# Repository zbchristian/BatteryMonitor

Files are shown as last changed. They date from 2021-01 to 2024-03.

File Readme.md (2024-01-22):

Battery Monitor with low energy Bluetooth readout
=================================================
Measure and display the 
- capacity in Ampere hours (Ah) of a battery
- the voltage of the battery (V)
- the current flowing from/to the battery (A)

of a camper/mobil home 12V battery on an Android Smartphone.

The monitor is based on three modules (DC-DC converter, ESP32, ADS1115), which are placed either on a bread board or a PCB. 
The schematic and the layout of this base board can be found in the Eagle folder.

Depending on the used firmware, the device pulls about 10mA (25mA) from the 12V battery. An additional 8-9mA are drawn by the Hall current sensor.

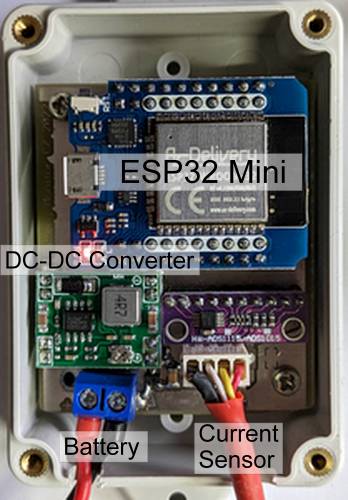
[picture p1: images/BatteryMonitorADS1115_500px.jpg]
Prototype Prototype of the Battery Monitor

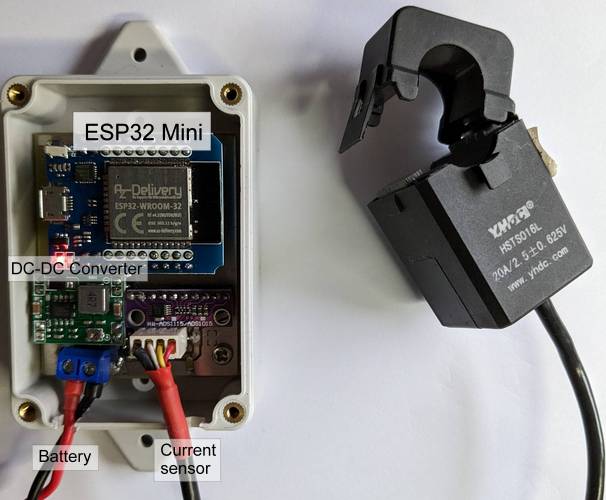
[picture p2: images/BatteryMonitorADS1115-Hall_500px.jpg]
Prototype with Hall sensor Prototype of the Battery Monitor with split core current sensor

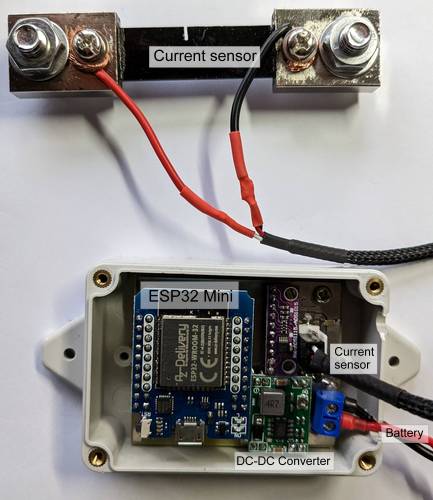
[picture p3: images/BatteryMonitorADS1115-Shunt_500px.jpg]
Prototype with shunt Prototype of the Battery Monitor with shunt


Hardware
========
* ESP32 board (Mini)
* Current sensor (Hall sensor to measure the magnetic field, or shunt resistor) 
* Step-down regulator (DC-DC Buck converter)
  * Input: 10V-20V
  * Output: 5.8V (adjustable version)
  * Max. current: 1A
* ADS1115 16 bit ADC

The 5.8V output voltage of the DC-DC converter is due to the fact, that the current sensor (Hall sensor) and the ADC require very stable 5V. 
This is provided by the 5V regulator MCP1702/1703. The ESP32 module has its own 3.3V regulator and can handle up to 6V on the Vcc pin. 

For a version utilizing the internal ADC, see the [Readme](Readme_internalADC.md).

Current Sensor
==============
A split core current sensor with a Hall sensor or a shunt resistor is used to measure the current.

Hall Sensor
-----------
Advantage: sensor works contactless. No need to mess with the cabling, since the sensor is just placed around one of the battery cables.

Utilized model: YHDC HSTS016L +-20A
- 2.5+-0.625V 
- reference voltage 2.5V

Shunt Resistor
--------------
A commercial shunt suitable for a high current (e.g. 100A) is placed into the ground connection to the battery. The voltage drop is small (e.g. 70mV for 100A).
The ADS1115 allows to change the voltage range down to +-256mV. This makes it suitable to measure the current with sufficient precision, without the need of an additional amplifier.

The reached resolution is for both cases about 50mA.

Analog to digital conversion
============================
The ADC ADS1115 with 16 bit resolution is readily available as a module. It exhibits 4 channels, a wide adjustable voltage range, a build in amplifier and can directly measure voltage differences.  

Android APP
===========
Developed with the MIT App-Inventor2
- Low energy bluetooth (BLE) connection to the ESP32
- Main Screen with current, voltage, capacity
- Settings window 

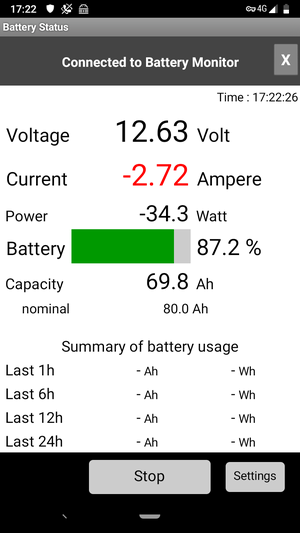
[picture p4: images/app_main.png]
Battery Monitor APP main screen Battery Monitor APP - main screen

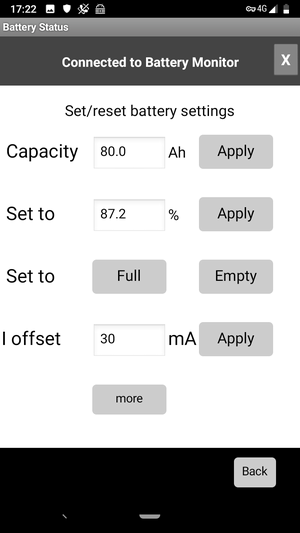
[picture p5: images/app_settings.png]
Battery Monitor APP settings Battery Monitor APP - settings


Software
========
The Arduino IDE is used for the code development. 
Three different versions of the ESP32 firmware exist:
- Utilize the internal ADC ([code](./BatteryMonitor_internal_ADC/BatteryMonitor_internal_ADC.ino))
- Utilize an ADS1115 external ADC ([code](./BatteryMonitor_ADS1115/BatteryMonitor_ADS1115.ino))
- UTilize an ADS1115 external ADC and reduce the power by going into the light sleep mode of the ESP32 The ([code](./BatteryMonitor_lowpower/BatteryMonitor_lowpower.ino))

Requires packages
-----------------
- ESP32 support with BLE and Wire
- ADS1115_WE by Wolfgang Ewald

Concept
-------
- Settings: define time intervals and used channels in the `#define` section of the code
- Setup: reduce CPU clock to save power, setup timers and the external ADC
- Loop: Read the battery voltage and current, calculate the Ah and power and store current battery state to flash
- The BLE connection is initialized by the phone
- A sign-on message is expected by the ESP32. This is a hash value of the current time (salt) and a pre-shared pass phrase. 
- If the message is not received, the BLE connection is terminated.
- For the first 60 seconds the connection is possible without the passphrase
- Data are send to the APP every second as a block of 20 bytes. The values are 16 bit integer values, which have been scaled to reflect the predefined number of significant digits. 

The versions differ mainly in the way the timing is handled. 

The first two versions utilize a 1msec timer interrupt to define time intervals and trigger time dependent 
actions (reading the voltage/current value, calculate battery capacity, transmit via BT). 

The third version handles the timing once per loop() iteration: 
- the loop is running once every 100msec
- the corresponding delay is done either as a standard delay (BT activated) or by the ´light sleep´ mode (BT off) of the ESP32. 
These states are alternating with 5sec BT off and 1sec BT on until a phone connects.
- while BT is off, the CPU frequency is reduced from 80 Mhz down to 20 MHz, which saves an additional 3-4mA @ 12V

In total this reduces the required current from about 25mA down to approx 4mA @ 12V, when the device is in idle mode (BT off). 

Status Printout of the Device
-----------------------------
An USB connection to the ESP32 allows to view the status print out of the device. Connect a terminal program to the corresponding virtual serial port (e.g. COM port).
The measured values and status infomrmations are printed to the terminal and allow to perform the calibration of the sensors.  

Calibration
===========
The calibration of the battery voltage and current measurement is required.

Battery Voltage
---------------
The measured voltage might vary due to resistor variations. The default voltage divider reduces the voltage by a factor of 0.25 ( 10k/(10k+30k) ). 
This factor is defined as `R12V`.
In addition a small voltage offset might be present. This should be measured with a good voltage meter and the corrections entered into the source code 
function `Vcal12`.

Current Sensor
--------------
A Hall sensor contains active components and the voltage to current conversion should be checked. An voltage offset leads to a none zero current displayed for 0 Amps.
The printout messages on a connected terminal allows to compare the measured values with the applied voltage/current. Enter the corrected values into the functions `VcalSensor` and `V2Amps`. 
Non linear dependencies might be entered into the latter function as well. 

Misc
====
On the PCB three additional IO pins are available on pin headers (IO2, IO4, IO5). These are not yet utilized and can be used to attach more hardware. The pin header for 
IO5 provides in addition 3.3V, which can be used to connect an active touch button (e.g. based on the TTP223 chip).

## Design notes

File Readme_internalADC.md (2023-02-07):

Battery Monitor with low energy Bluetooth readout
=================================================
Measure and display the 
- capacity in Ampere hours (Ah) of a battery
- the voltage of the battery (V)
- the current flowing from/to the battery (A)

of a camper/mobil home 12V battery on an Android Smartphone.

Prototype exists, but the schematic not completed yet.

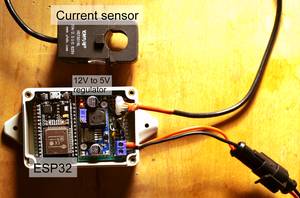
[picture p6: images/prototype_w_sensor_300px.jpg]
Prototype Prototype of the Battery Monitor

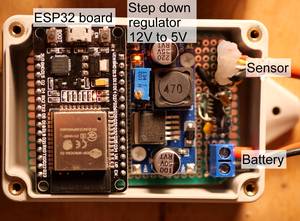
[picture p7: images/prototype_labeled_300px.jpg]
Prototype close up Prototype of the Battery Monitor (close up)


Hardware
========
* ESP32 board
* Current sensor to measure the magnetic field or a shunt resistor 
* Step-down regulator (DC-DC Buck converter)
  * Input: 10V-20V
  * Output: 5V (fixed or adjustable)
  * Current: 1A
* Dual OpAmp

Current Sensor
==============
A split core current sensor with a Hall sensor is used to measure the current.

Advantage: sensor works contactless. No need to mess with the cabling, since the sensor is just placed around one of the battery cables.

Utilized model: YHDC HSTS016L +-20A
- 2.5+-0.625V (buffered by an OpAmp) 
- reference voltage 2.5V (buffered by an OpAmp) 

The reached resolution is about 50mA.

Analog to digital conversion
============================
Internal 12-bit ADC of the ESP32 processor. The ADC is quite noisy and an averaging (low pass filter) is used in the software 
in order to achieve the resolution of about 50mA.

Android APP
===========
Developed with the MIT App-Inventor2
- Low energy bluetooth (BLE) connection to the ESP32
- Main Screen with current, voltage, capacity
- Settings window 

Battery Monitor APP main screen Battery Monitor APP - main screen
Battery Monitor APP settings Battery Monitor APP - settings

Software
========
The Arduino IDE is used for the code development.

- The BLE connection is initialized by the phone
- A sign-on message is expected by the ESP32. This is a hash value of the current time (salt) and a pre-shared pass phrase. 
- If the message is not received, the BLE connection is terminated.
- Data are send to the APP every second as a block of 20 bytes. The values are 16 bit integer values, which have been scaled to reflect the predefined number og significant digits.

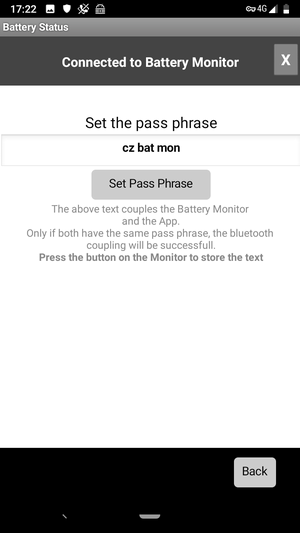
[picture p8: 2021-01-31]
images/app_passphrase.png

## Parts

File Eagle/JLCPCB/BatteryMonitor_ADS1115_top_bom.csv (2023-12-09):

Comment | Designator | Footprint | LCSC Part #
1k | R3 R4 R5 | R1206
1u | C2 C3 C5 | C1206
2u | C4 C7 | C1206
10k | R2 | R1206
33k | R1 | R1206
100n | C1 | C1206
CGRM4001-G | D1 | SOD-123_MINI-SMA
MCP1703CB | IC1 | SOT23

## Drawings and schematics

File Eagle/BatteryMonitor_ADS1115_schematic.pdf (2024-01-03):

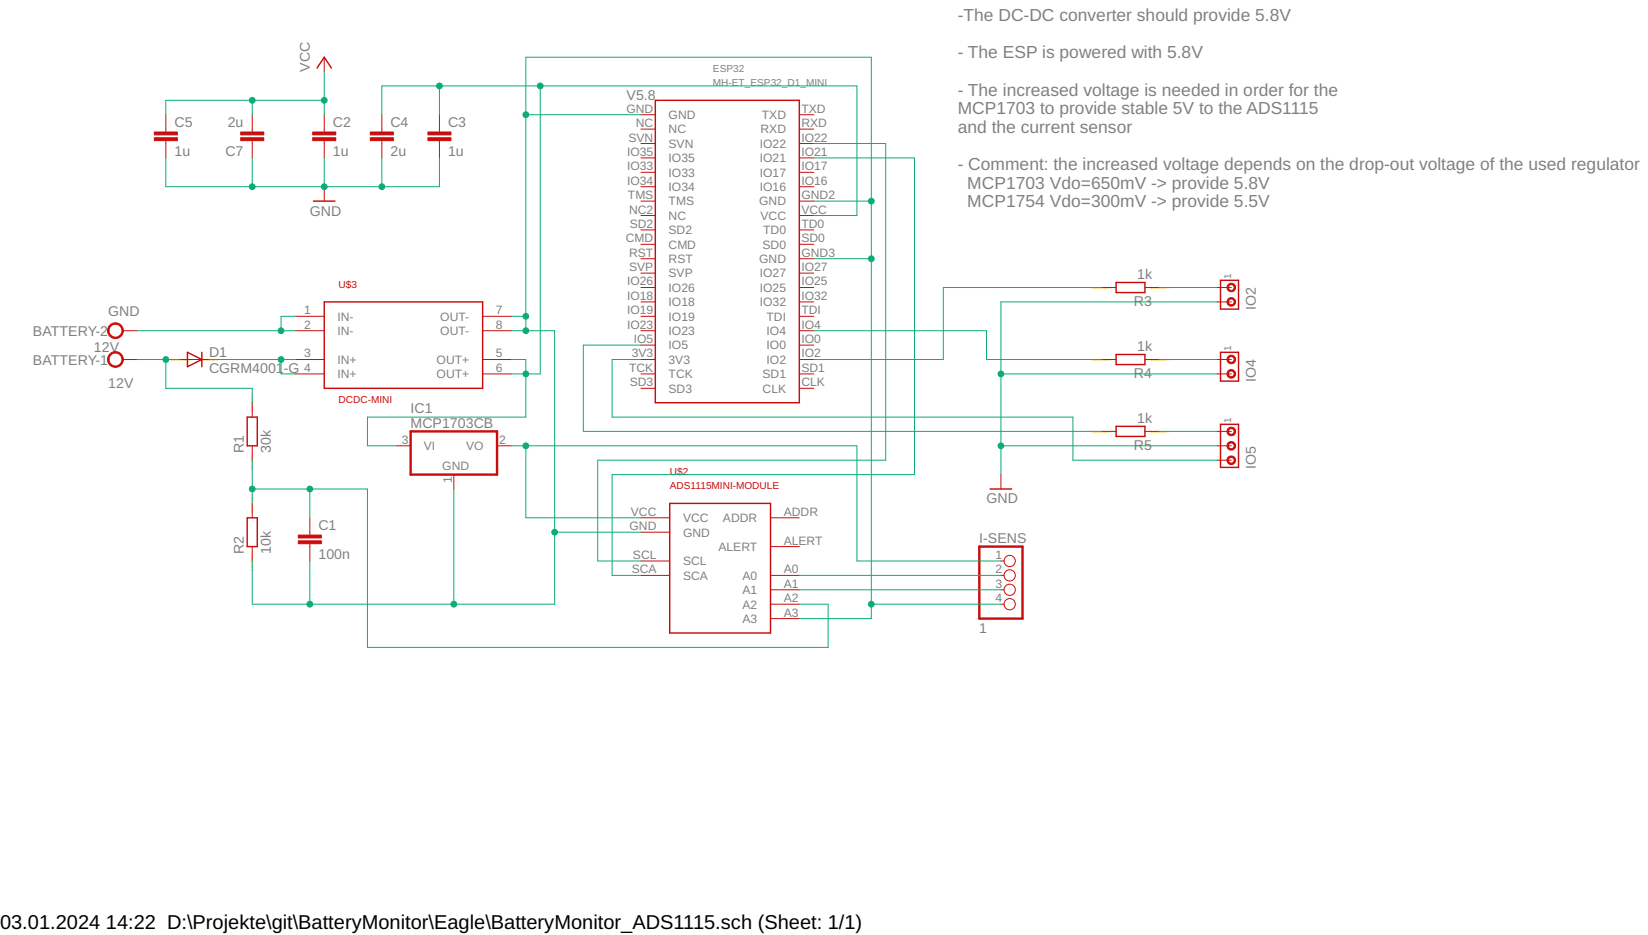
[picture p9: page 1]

-The DC-DC converter should provide 5.8V

- The ESP is powered with 5.8V

- The increased voltage is needed in order for the
MCP1703 to provide stable 5V to the ADS1115
and the current sensor

IO21
IO17

- Comment: the increased voltage depends on the drop-out voltage of the used regulator
MCP1703 Vdo=650mV -> provide 5.8V
MCP1754 Vdo=300mV -> provide 5.5V

VCC

SpiceOrder 1 SpiceOrder 2

03.01.2024 14:22 D:\Projekte\git\BatteryMonitor\Eagle\BatteryMonitor_ADS1115.sch (Sheet: 1/1)

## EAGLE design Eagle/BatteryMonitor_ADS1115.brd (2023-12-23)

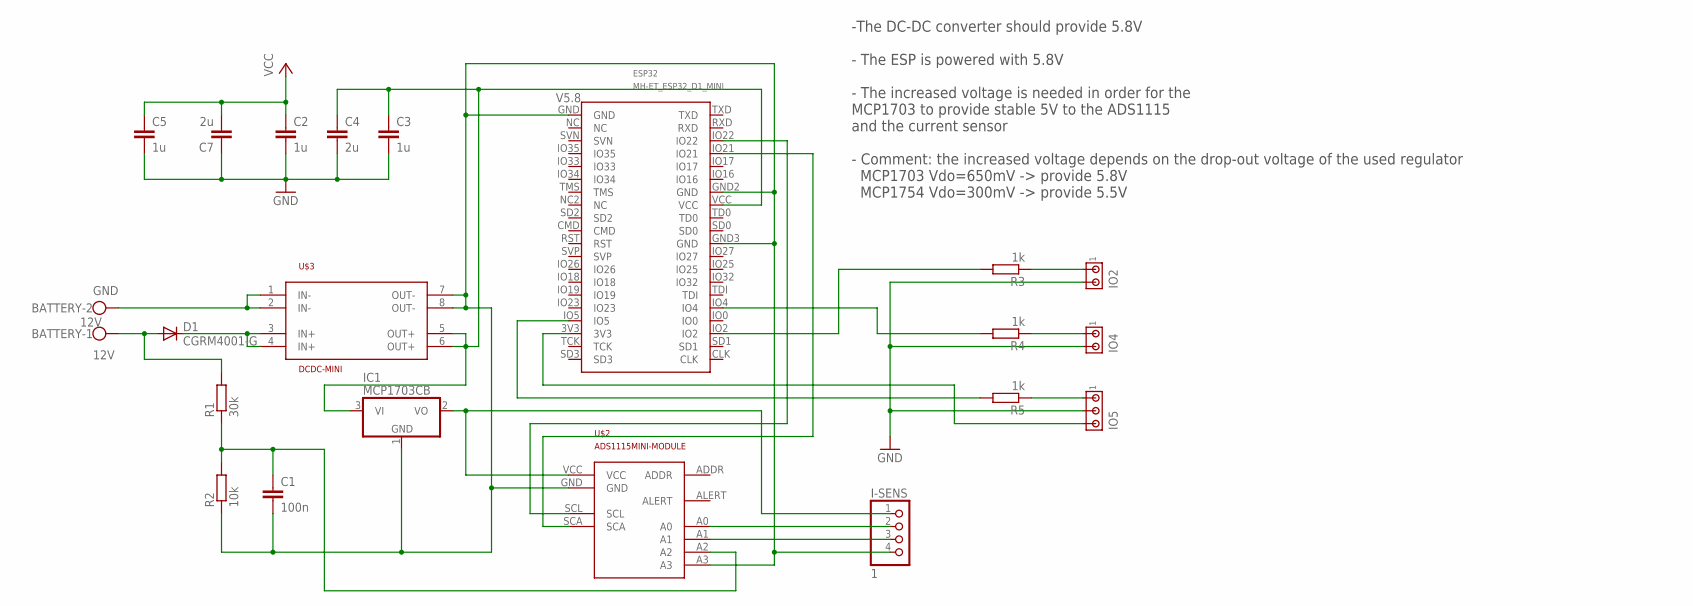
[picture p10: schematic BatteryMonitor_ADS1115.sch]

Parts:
BATTERY: 12V; W237-102
C1: 100n; C1206
C2, C3, C5: 1u; C1206
C4, C7: 2u; C1206
D1: CGRM4001-G; SOD-123_MINI-SMA
ESP32: MH-ET_ESP32_D1_MINI
I-SENS: 1; 1X04/90
IC1: MCP1703CB; SOT23
IO2, IO4: MTA02-100; 10X02MTA
IO5: MTA03-100; 10X03MTA
R1: 30k; R1206
R2: 10k; R1206
R3, R4, R5: 1k; R1206
U$2: ADS1115MINI-MODULE; ADS1115
U$3: DCDC-MINI

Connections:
12V: BATTERY.1, D1.A, R1.2
GND: BATTERY.2, C1.2, C2.2, C3.2, C4.2, C5.2, C7.1, ESP32.GND, ESP32.GND2 (GND), ESP32.GND3 (GND), I-SENS.4, IC1.1 (GND), IO2.2, IO4.2, IO5.2, R2.1, U$2.A3, U$2.GND, U$3.1 (IN-), U$3.2 (IN-), U$3.7 (OUT-), U$3.8 (OUT-)
unnamed: IO5.1, R5.1
unnamed: ESP32.IO2, R3.2
unnamed: ESP32.IO4, R4.2
unnamed: I-SENS.2, U$2.A0
unnamed: ESP32.IO5, R5.2
unnamed: I-SENS.3, U$2.A1
unnamed: ESP32.IO21, U$2.SCA
unnamed: ESP32.IO22, U$2.SCL
unnamed: C1.1, R1.1, R2.2, U$2.A2
unnamed: IO4.1, R4.1
unnamed: IO2.1, R3.1
unnamed: ESP32.3V3, IO5.3
V5.8: C3.1, C4.1, ESP32.VCC, IC1.3 (VI), U$3.5 (OUT+), U$3.6 (OUT+)
V12: D1.C, U$3.3 (IN+), U$3.4 (IN+)
VCC: C2.1, C5.1, C7.2, I-SENS.1, IC1.2 (VO), U$2.VCC

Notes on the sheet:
-The DC-DC converter should provide 5.8V - The ESP is powered with 5.8V - The increased voltage is needed in order for the MCP1703 to provide stable 5V to the ADS1115 and the current sensor - Comment: the increased voltage depends on the drop-out voltage of the used regulator MCP1703 Vdo=650mV -> p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

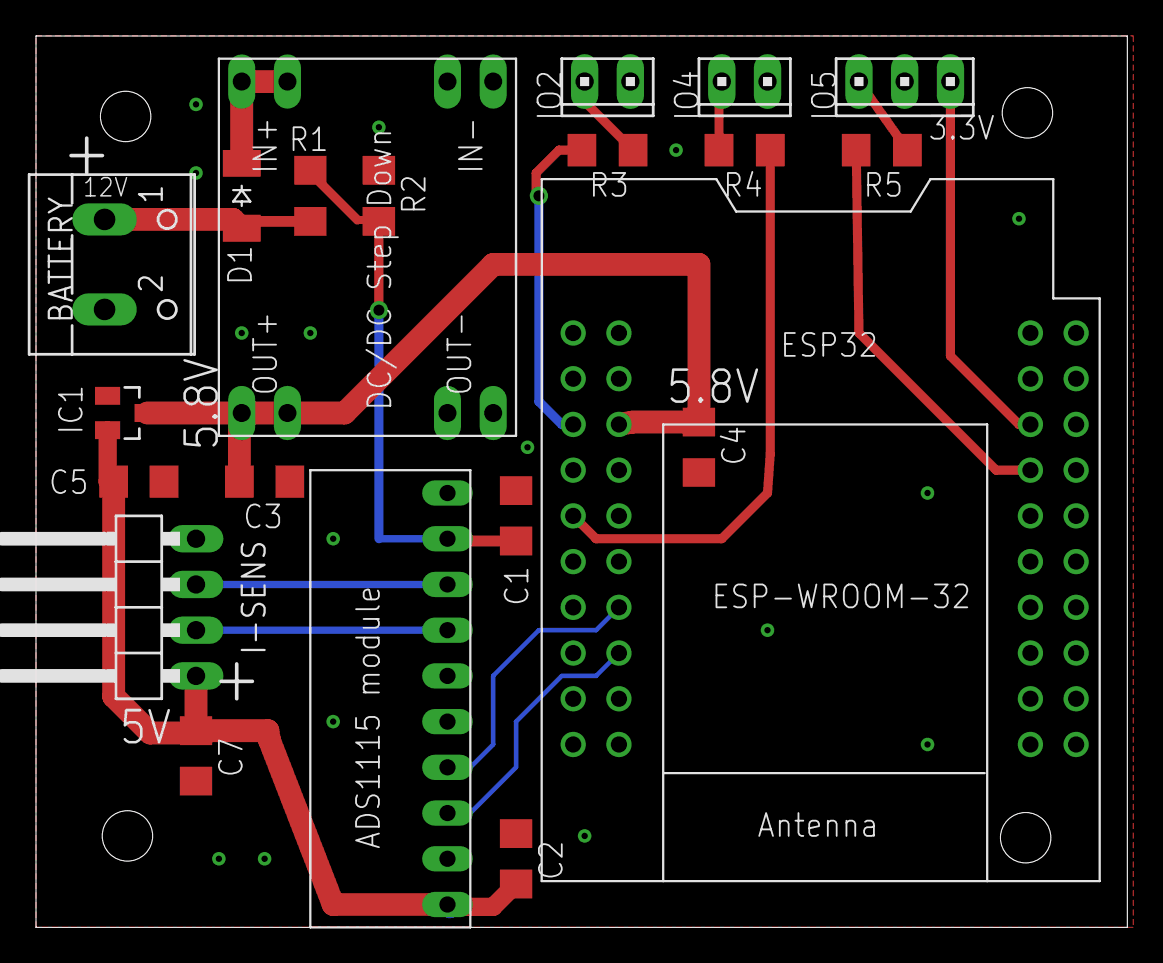
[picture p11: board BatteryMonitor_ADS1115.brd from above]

Board: 2 copper layers, 60.6 x 49.5 mm, 21 parts (0 on the bottom side), 17 nets.

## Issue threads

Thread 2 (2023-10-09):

How to Use Shunt

thinkupplus, 2023-10-09:
We want to find voltage and current values using shunt resistance.
How do I wire the shunt resistor connection? It's hard to tell from the image.
Where should I connect to 0,1,2,3 of ADS1115?
And even if I save the capacity in the app, it is not reflected?
What did I do wrong?

zbchristian, 2023-10-09:
How to attach the shunt: in the program you find `adc_sensor` defined as the difference between channel 0 and channel 1 of the ADC.

The inputs of the ADC are:
A0: Sensor
A1: Sensor
A2: battery voltage
A3: GND

Not sure what you mean, that the capcaity is not reflected in App. Please be more specific.
Does the App connect to the device? What is visible on the display?

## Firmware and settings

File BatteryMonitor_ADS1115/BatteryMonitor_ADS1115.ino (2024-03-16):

/*
BATTERY MONITOR WITH CURRENT SPLIT CORE WITH HALL SENSOR
========================================================
Sensor model YHDC HSTS016L or a shunt resistor

ADC: ADS1115 module via I2C
- Powered by 5V
- Voltage range 4V (Hall sensor) or 256mV (shunt resistor)

- Channel A3 - GND
- Channel A2 - 12V battery voltage (divided by (10+30)/10=4.0) = approx 3V
- Channel A1 - reference voltage of the sensor (nom. 2.5V) 
- Channel A0 - Sensor reading typically 2.5V +- 0.625V or +-75mV (shunt)

Precision: noise of hall sensor allows for about 50mA precision

Values are transmitted via Low Energy Bluetooth to a smartphone app
- all values in uint16 format
- voltage (V) * 100
- current (A) * 100
- power (W) * 10
- nominal and current battery capacity (Ah) * 10
- percentage available (%) * 10

Nominal and current capacity are stored in FLASH memory every 30 seconds

Commands accepted over BLE (string)
===================================
s100 - set current capacity to 100% (full)
s000 - set current capacity to 0% (empty)
scxxxxxx - set nominal capacity to xxxxxx/10 Ah
s%xxxx - set percentage of the current capacity to xxxx/10% (e.g. s%785 -> 78.5%)
soxxxx - set the current offset in milli Amps
sixxxx - set the pre-shared pass phrase used for the hash value of the sign on message (max 9 characters)
ghxxxx - get history data (xxxx = time window in secs, if 0 : send all data) 


THE BATTERY MONITOR DEBUG INFOS
===============================
Connect the ESP32 via USB to a computer and open a terminal program and connect to 
the corresponding serial interface (e.g. COM port)

CZ July 2020/2023

*/

// set the sensor type
//#define CURRENT_SHUNT
#define CURRENT_HALL

#include <stdlib.h>

#include <BLEDevice.h>
#include <BLEUtils.h>
#include <BLEScan.h>
#include <BLEAdvertisedDevice.h>
#include <BLEServer.h>
#include <BLE2902.h>

#include "esp32-hal-cpu.h"

#include "mbedtls/md.h"

/*
extern "C" {
  #include "soc/syscon_struct.h"
}
#include "soc/sens_struct.h"
#include <driver/adc.h>
#include "esp_adc_cal.h"
*/

#include<ADS1115_WE.h> 
#include<Wire.h>
#define I2C_ADDRESS 0x48

#include <Preferences.h>
Preferences persistentStore;  // provides access to the Flash memory


#ifndef CURRENT_HALL
#define CURRENT_CURRENT
#endif
#ifndef CURRENT_SHUNT
#define CURRENT_HALL
#endif

int16_t scale16(float ,float );
void clearStats(void);
void calcStats();

BLEServer *pServer=NULL;
BLEService *pService=NULL;
BLECharacteristic *pCharacteristic_rx;
BLECharacteristic *pCharacteristic_tx;

bool deviceConnected = false;

ADS1115_WE adc = ADS1115_WE(I2C_ADDRESS);

const ADS1115_MUX adc12V        = ADS1115_COMP_2_3; // Diff channel 2 and 3: Battery Voltage
const ADS1115_MUX adcSensor     = ADS1115_COMP_0_1; // Diff channel 0 and 1 : Sensor signal

const ADS1115_RANGE RangeV12    = ADS1115_RANGE_4096;
#ifdef CURRENT_HALL
const ADS1115_RANGE RangeSensor = ADS1115_RANGE_4096;
#else
const ADS1115_RANGE RangeSensor = ADS1115_RANGE_0256;
#endif

#define LED     LED_BUILTIN
#define BUTTON  GPIO_NUM_0   // this is the boot button - NOT AVAILABLE in ESP32 mini modules

hw_timer_t * msTimer = NULL;

DRAM_ATTR unsigned long msTime;
unsigned long deltaTime=0;
unsigned long msLast=0;

#define DefaultSignOnMsg  "123456"   // pre-shared message (max 9 characters) for which a sha256 hash is send by the client
#define maxSignonLen      10

#define currentBin        0.05       // current only displayed in units of 50mA

#define R12V              0.25      // measured - ideal 10/(10+30)=1/4

#define chargeEff		      0.95	    // charging efficiency - AGM/GEL: ~95% , standard lead acid: ~80%

// define time (ms) between the execution of certains functional codes
#define doSave            30000 // ms to save data to EPPROM 
#define doADC             300   // ms to read data from ADC
#define doLED             350   // ms to toggle the LED 
#define doBLE             2000  // ms to send data over BLE
#define doDelay           10    // ms to sleep in LOOP
#define waitSignon        2000  // ms to wait for the signon message

#define timeNoSignon 60000 // ms to wait for a connection without signon message (starts when button is pressed or after reset)

DRAM_ATTR boolean   isSave=false;
DRAM_ATTR boolean   isADC=false;
DRAM_ATTR boolean   isLED=false;
DRAM_ATTR boolean   isBLE=false;
DRAM_ATTR boolean   isAVR=false;
DRAM_ATTR boolean   isValidClient;
DRAM_ATTR int       countSignon;
DRAM_ATTR long      countNoSignon;
DRAM_ATTR boolean   isNoSignon;
DRAM_ATTR int       ncharSignon;
DRAM_ATTR boolean   isReceiveSignon;

float  fCPU;  // CPU frequency in MHz

double filtered12V = -1.0;
double filteredSensor= -1.0;
double BatCapNominal=0.0;
double BatCap  = 0.0;   
double BatIoff = 0.0;
double VBat    = 0.0;
double AmpsBat = 0.0;

const unsigned int timeHistory = 7*24*60*60*1000; // length of history in milli seconds - 7 days
const unsigned int histBin     = 6*60*1000;       // store average values for every n ms - 6 min
const unsigned int nhistory    = timeHistory/histBin; // # of values to store for the timeHistory

float *histAmps;
float *histAh;
float *histVolts;
float avrAmps = 0.0;
float avrAh   = 0.0;
float avrVolts= 0.0;
float statAh[4]   = {-10000.0,-10000.0,-10000.0,-10000.0};  // Ah store statistic for 1h, 6h, 12h and 24h
float statWh[4]   = {-10000.0,-10000.0,-10000.0,-10000.0};  // energy (Wh) store statistic for 1h, 6h, 12h and 24h
unsigned int  histPos = 0;

// See the following for generating UUIDs:
// https://www.uuidgenerator.net/

#define SERVICE_UUID           "0000ffe0-0000-1000-8000-00805f9b34fb" // UART service UUID
#define CHARACTERISTIC_UUID_TX "0000ffe1-0000-1000-8000-00805f9b34fb"
#define CHARACTERISTIC_UUID_RX "0000ffe2-0000-1000-8000-00805f9b34fb"

char txt[100];

char *signOnText;
#define lenSignOn  100

double Vcal12(double v)         { return v-0.05; } // calibrated voltage of ADC 
double get12V(double v)         { return (Vcal12(v))/R12V; }

#ifdef CURRENT_HALL
// The Hall sensor requires calibration
// - check the reference voltage (serial debug port) at 0 Amps and correct VcalSensor 
double VcalSensor(double v)     { return v-0.0027; } // Hall - calibrated voltage of Sensor measurement
// Voltage to current might not be completely linear, but this is ignored here
double V2Amps(double dV)        { return 26.73*dV - 0.0; } // Hall sensor - calibrated voltage to current function

#else
// The Shunt sensor requires calibration
// - check the reference voltage (serial debug port) at 0 Amps and correct VcalSensor 
double VcalSensor(double v)     { return v+0.00014; } // Shunt - calibrated voltage of Sensor measurement
// Voltage to current should be linear. Check marking on the shunt, e.g. 85mV @ 100A 
double V2Amps(double dV)        { return 100/0.085*dV; } // Shunt - calibrated voltage to current function
#endif
double getCurrent(double Vdiff) { return V2Amps(VcalSensor(Vdiff)); }

#define sign(x) ((x>=0) ? 1 : -1)

// nominal and current battery capacity is retrieved/stored from/in Flash memory 
void persistentBatCapacity(boolean isGet=true) {
  double val;
  if(isGet) {
    BatCapNominal = persistentStore.getDouble("CapNominal", 100.0);
    BatCap = persistentStore.getDouble("CapCurrent", 10.0);
    BatIoff = persistentStore.getDouble("Ioffset", 0.0);
  } else {
    // limit the precision to reduce FLASH write operations
    val=BatCapNominal;
    val = (long)(val/0.01+0.5)*0.01; // 2 decimal digits of precision
    if (fabs(persistentStore.getDouble("CapNominal", 100.0)-val) > 0.005) persistentStore.putDouble("CapNominal", val);
    val=BatCap;
    val = (long)(val/0.001+0.5)*0.001;  // 3 decimal digits of precision
    if (fabs(persistentStore.getDouble("CapCurrent",10.0)-val) > 0.0005) persistentStore.putDouble("CapCurrent", val);
    val=BatIoff;
    val = (long)(val/0.001+0.5)*0.001;  // 3 decimal digits of precision
    if (fabs(persistentStore.getDouble("Ioffset",0.0)-val) > 0.0005) persistentStore.putDouble("Ioffset", val);
  }
}

mbedtls_md_context_t ctx;
mbedtls_md_type_t md_type = MBEDTLS_MD_SHA256;
byte sha256Res[32];
char sha256hash[65];

// calculate the sha256 hash and return the hash as an array of 32 bytes 
void hashSHA256(char *payload, int len, byte *result) {
  mbedtls_md_init(&ctx);
  mbedtls_md_setup(&ctx, mbedtls_md_info_from_type(md_type), 0);
  mbedtls_md_starts(&ctx);
  mbedtls_md_update(&ctx, (const unsigned char *) payload, len);
  mbedtls_md_finish(&ctx, result);
  mbedtls_md_free(&ctx);
 }

long long timemillisecs=0;

// signon message is a sha256 hash of the predefined sign on message with the appended time in ms since 1970 of the client
// The time string is send as clear text "time hash" (salt)  
bool checkSignon() {
  int posBlank = strcspn(signOnText," ");
  if (posBlank < 0 || posBlank >= 20) return false;
  char strTime[20];
  strncpy(strTime,signOnText,posBlank);
  strTime[posBlank] = '\0';
  long long timems = atoll(strTime);
  if (timems <= timemillisecs) return false;
  char *strhash = &signOnText[posBlank+1];
  if(strlen(strhash) < 64) return false; 
  int lenSignon=persistentStore.getString("signon").length();
  int len = strlen(strTime)+lenSignon;
  if(len > 120) return false;
  char *txt2hash = (char*)malloc(len+1);
  strncpy(txt2hash,persistentStore.getString("signon").c_str(),lenSignon);
  strncpy(&txt2hash[lenSignon],strTime,strlen(strTime));
  txt2hash[len]='\0';
  byte result[32];
  hashSHA256(txt2hash,len,sha256Res);
  for(int i= 0; i<32; i++) sprintf(&sha256hash[i*2], "%02x", (int)sha256Res[i]);
  sha256hash[64]='\0';
  Serial.println();
  Serial.println(strhash);
  Serial.println(sha256hash);
  if (strcmp(strhash,sha256hash)==0) {
    timemillisecs = timems;
    return true;  
  } 
  return false;
}

const int16_t SignonOK[2]={2,0};
void receiveSignon(char *txt, int txtlen) {
  if (!isReceiveSignon || txtlen <=0) return;
  int dlen=strlen(signOnText);
  int len = min(txtlen,lenSignOn-dlen);
  strncpy(&signOnText[dlen],txt,len);
  signOnText[dlen+len]='\0';
  isReceiveSignon = strlen(signOnText)<ncharSignon;
  if(strlen(signOnText) == ncharSignon) { // we received the whole signon message
    // save the message
     persistentStore.putString("signon",signOnText);
    Serial.println();
    Serial.print("New Signon message -");
    Serial.print(signOnText);
    Serial.println("- done");
    isNoSignon=false;
    
    pCharacteristic_tx->setValue((uint8_t*)SignonOK,sizeof(SignonOK)*2); // acknowledge reception 
    pCharacteristic_tx->notify(); 
  }
}

void BLEAdvertise(bool isStart) {
  if (isStart) {
    // Start advertising
    pServer->getAdvertising()->start();
    Serial.println("Waiting for a client connection ...");
  } else {
    pServer->getAdvertising()->stop();
    Serial.println("Stopped BLE advertisment ...");
  }
  isNoSignon=false;
}

class MyServerCallbacks: public BLEServerCallbacks {
    void onConnect(BLEServer* pServer) {
      Serial.println("Client connects");
      deviceConnected = true;
      signOnText[0]='\0';
      isValidClient = isNoSignon;
    };

    void onDisconnect(BLEServer* pServer) {
      Serial.println("Client disconnects");
      deviceConnected = false;
      isValidClient = false;
      BLEAdvertise(true);
    }
};
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
void loop() {

  if( isSave ) {
    persistentBatCapacity(false); // write current values to EEPROM
    isSave = false;  
  }

  if( isADC) {
    deltaTime = msTime - msLast;
    msLast = msTime;
    filtered12V = getFilteredVoltage( getADC_V(adc12V, RangeV12), filtered12V ); 
    filteredSensor = getFilteredVoltage( getADC_V(adcSensor, RangeSensor), filteredSensor ); 
    VBat = get12V(filtered12V);
    AmpsBat = getCurrent(filteredSensor);
    sprintf(txt,"Time diff [ms] %d, VBat [V] %10.2f, Vsens [mV] %10.3f, Current [A] %10.3f - ",deltaTime,VBat,filteredSensor*1000, AmpsBat);       
    Serial.println(txt);

    AmpsBat = getCurrent(filteredSensor);
    AmpsBat = (long)(AmpsBat/currentBin)*currentBin - BatIoff;
    eff = sign(AmpsBat)<0 ? 1.0 : chargeEff;	// take efficiency of charging (I>0) into account
    BatCap += AmpsBat*deltaTime/1000/3600.0*eff; // calculate the change of the battery capacity
    if ( BatCap <= 0.0) BatCap = 0.0;

    ++nAvr;
    avrVolts += VBat;
    avrAmps += AmpsBat;
    avrAh += BatCap;
        
    isADC = false;  
  }

  if( isAVR && nAvr > 0) {
    histVolts[histPos] = avrVolts/nAvr;
    histAmps[histPos] = avrAmps/nAvr;
    histAh[histPos++] = avrAh/nAvr;
    if (histPos >= nhistory) histPos = 0;
    sprintf(txt,"Volts %10.2f, Amps %10.2f, Ah %10.1f - ",avrVolts/nAvr, avrAmps/nAvr, avrAh/nAvr);       
    Serial.println(txt);
    avrVolts = avrAmps = avrAh = 0.0;
    nAvr = 0;
    calcStats();
    isAVR = false;
  }



  if ( isBLE && deviceConnected && isValidClient) {
    int16_t txValue[10]={0.0};

//    pService->stop();

    sprintf(txt,"%10.1f,%10.1f - ",filtered12V, filteredSensor);       
    Serial.print(txt);
    
    float PowerBat = VBat*AmpsBat; // power
    sprintf(txt,"%10.4f,%10.4f",filtered12V, filteredSensor);
    Serial.println(txt);
    memset(txValue, 0, sizeof(txValue));
    txValue[0] = 0; // mark data as current values
    txValue[1] = scale16(VBat,100); // transmit with 2 digits precision
    txValue[2] = scale16(AmpsBat,100);  // transmit with 2 digits precision
    txValue[3] = scale16(PowerBat,10); // transmit with 1 digit precision
    txValue[4] = scale16(BatCapNominal,10); 
    txValue[5] = scale16(BatCap,10);
    float bPerc = BatCap/BatCapNominal*100.0;
    if (bPerc < 0.0) bPerc = 0.0;
    if (bPerc > 100.0) bPerc = 100.0;
    txValue[6] = scale16(bPerc,10); 
    txValue[7] = scale16(BatIoff*1000,1); 
    
//    txValue[7] = scale16(filtered12V,1);
//    txValue[8] = scale16(filteredSensor,1);

    pCharacteristic_tx->setValue((uint8_t*)txValue,20); // To send 10 uint16 values
    pCharacteristic_tx->notify(); // Send the values to the app!
    memset(txValue, 0, sizeof(txValue));

    txValue[0] = 1; // mark data as statistics
    txValue[1] = scale16(statAh[0],10); // transmit with 1 digits precision
    txValue[2] = scale16(statAh[1],10); // transmit with 1 digits precision
    txValue[3] = scale16(statAh[2],10); // transmit with 1 digits precision
    txValue[4] = scale16(statAh[3],10); // transmit with 1 digits precision
    txValue[5] = scale16(statWh[0],1); // transmit with 0 digits precision
    txValue[6] = scale16(statWh[1],1); // transmit with 0 digits precision
    txValue[7] = scale16(statWh[2],1); // transmit with 0 digits precision
    txValue[8] = scale16(statWh[3],1); // transmit with 0 digits precision

    pCharacteristic_tx->setValue((uint8_t*)txValue,20); // To send 10 uint16 values
    pCharacteristic_tx->notify(); // Send the values to the app!

//    pCharacteristic_tx->setValue("Hello!"); // Sending a test message
//    pCharacteristic_tx->setValue(txt);
//    if(isSetSignonOK) {
//      pCharacteristic_tx->setValue("siOK"); // acknowledge reception 
//      pCharacteristic_tx->notify(); 
//      isSetSignonOK=false;
//    }
  }
  isBLE = false;

  if (deviceConnected && countSignon > waitSignon && !isValidClient && !isNoSignon) { // check if signon message has been received in time
    pServer->removePeerDevice(pServer->getConnId(),true);
    deviceConnected = false;
    countSignon = 0;
  }
  delay(doDelay);
}

const int n1h  =  1*60*60*1000/histBin; // # vals to integrate for 1h 
const int n6h  =  6*60*60*1000/histBin; // # vals to integrate for 6h 
const int n12h = 12*60*60*1000/histBin; // # vals to integrate for 12h 
const int n24h = 24*60*60*1000/histBin; // # vals to integrate for 24h 

void calcStats() {
// loop backwards through the history arrays (ring buffer)
  int i;
  int n=0;
  int idx = histPos-1;  // start index
  for(i=0; i<4;++i) statAh[i]=statWh[i]=0.0;  // clear statistics
  for (i=0; i<n24h; ++i) {
    if(idx < 0) idx = nhistory -1;  // switch to the end of the array
    if(histAh[idx] < -999) break;    // value is not set yet -> break out of for loop 
    if(idx == histPos) break;       // this should never happen!
    if(n < n24h) {
      statAh[3] += histAmps[idx]*histBin/1000./3600.;  // calculate Ah 
      statWh[3] += histAmps[idx]*histVolts[idx]*histBin/1000.0/3600.; // calculate Wh
//      statAh[3] += histAh[idx];  // add up Ah - incorrect
//      statWh[3] += histAh[idx]*histVolts[idx]; // calculate Wh  - incorrect
  sprintf(txt,"n %d, idx %d, %10.4f ",n,idx,statAh[3]);       
  Serial.println(txt);
    }
    if(n < n1h) { statAh[0] = statAh[3]; statWh[0] = statWh[3]; }
    if(n < n6h) { statAh[1] = statAh[3]; statWh[1] = statWh[3]; }
    if(n < n12h){ statAh[2] = statAh[3]; statWh[2] = statWh[3]; }
    ++n;
    --idx;
  }
  if(n==0) {
    for(i=0; i<4;++i) statAh[i]=statWh[i]=-10000.0;  // no data available    
  }
  sprintf(txt,"Ah  %10.2f 1h, %10.2f 6h, %10.2f 12h ",statAh[0],statAh[1],statAh[2]);       
  Serial.println(txt);
  sprintf(txt,"Wh  %10.2f 1h, %10.2f 6h, %10.2f 12h ",statWh[0],statWh[1],statWh[2]);       
  Serial.println(txt);
}

void sendHistory() {
  Serial.println("Send History");
  int16_t txValue[10]={0.0};
  int i=0;
  int n=0;
  int idx = histPos-1;  // start index
  while (i++ < nhistory && idx >= 0 && idx != histPos && histAh[idx] > -999 ) {
    sprintf(txt,"i = %d, idx = %d, histAh = %d",i, idx, histAh[idx]);
    Serial.println(txt);
    --idx;       
    ++n;  // get number of entries in history array
  }
  if (n==0) return;  // nothing to send
  sprintf(txt,"n = %d",n);
  Serial.println(txt);

  // loop backwards through the history arrays (ring buffer)
  txValue[0] = 3; // mark data as history package 
  txValue[1] = (int16_t)n*2;  // total number of values (voltage and Ah)
  txValue[2] = (int16_t)(histBin/1000*n); // total time of data in secs
  txValue[3] = (int16_t)(histBin/1000); // time width per bin in secs
  txValue[4] = (int16_t)((n*2)/5+1); // number of 20 byte packages 
  pCharacteristic_tx->setValue((uint8_t*)txValue,20); // To send 10 uint16 values
  pCharacteristic_tx->notify(); // Send the value to the app
  int iv=0;
  idx = histPos-1;  // start index
  for (i=0; i<n; ++i) {
    if(idx < 0) idx = nhistory -1;  // switch to the end of the array
    if(idx == histPos) break;       // this should never happen!
    txValue[iv++] = scale16(histAh[idx],10); // transmit with 1 digits precision
    txValue[iv++] = scale16(histVolts[idx],100); // transmit with 2 digits precision
    if(iv == 10) {
      pCharacteristic_tx->setValue((uint8_t*)txValue,20); // To send 10 uint16 values
      pCharacteristic_tx->notify(); // Send the values to the app!
      memset(txValue, 0, sizeof(txValue));
      iv=0;
    }
    --idx;
  }
  if(iv > 0) {
    pCharacteristic_tx->setValue((uint8_t*)txValue,20); // To send 10 uint16 values  
    pCharacteristic_tx->notify(); // Send the values to the app!
  }
}

int16_t scale16(float val,float fac) {
#define vmax16   32767.0
#define vmin16  -32768.0
  val = (val*fac)+sign(val)*0.5;  // scale and round 
  if ( val < vmin16) val = vmin16;
  if ( val > vmax16) val = vmax16;
  return (int16_t)val;
}

void clearStats() {
  for (int i=0; i<nhistory;++i) {
    histAmps[i] = -1000.0;
    histAh[i] = -1000.0;
    histVolts[i] = -1000.0;    
  }
}

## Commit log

2021-01-20 Bqttery Monitor based on ESP32 and BLE readout via MIT AppInventor APp
2021-01-22 Move ESp32 source into folder
2021-01-31 Add images of prototype and App
2021-02-27 Add Alert to display errors and progress Add procedure to receive history data. Not displayed yet
    [BatteryMonitor_internal_ADC.ino]
2023-01-31 ADS1115 as external ADC
    [BatteryMonitor_ADS1115.brd, BatteryMonitor_ADS1115.sch, BatteryMonitor_Nutzen_ADS1115.brd]
2023-01-31 Optimize part placement
    [BatteryMonitor_ADS1115.brd, BatteryMonitor_ADS1115.sch]
2023-01-31 Read and filter voltages from ADS1115
2023-02-02 Revert internal ADC version back to master
    [BatteryMonitor_ADS1115.ino, BatteryMonitor_internal_ADC.ino]
2023-02-02 Verbose print
2023-02-04 Update App for Android 12 and 13 and calibrate voltage and current
2023-02-05 Add current measurement with a shunt resistor
2023-02-05 Move internal ADC Readme_internalADC.md
2023-12-08 Change layout - all SMD on top
    [BatteryMonitor_ADS1115.brd, BatteryMonitor_ADS1115.sch, BatteryMonitor_ADS1115_top_bom.csv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]
2023-12-08 Correct description of DCDC output voltage
    [BatteryMonitor_ADS1115.brd, BatteryMonitor_ADS1115.sch]
2023-12-09 Update layout: add 3.3V to IO connector
    [BatteryMonitor_ADS1115.brd, BatteryMonitor_ADS1115.sch, BatteryMonitor_ADS1115_top_bom.csv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]
2023-12-23 Calibration done and documented
    [BatteryMonitor_ADS1115.brd, BatteryMonitor_ADS1115.sch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]
2023-12-29 Fix issue with BLE reconnect and changing the sign-on message
    [BatteryMonitor_ADS1115.ino]
2024-01-03 Add schematic as PDF
2024-01-20 Add low power version of the ESP32 firmware
2024-01-20 Update for the low power version
2024-01-20 Fix link and formatting
    [BatteryMonitor_lowpower.ino]
2024-01-21 correct time difference calculations and reduce CPU speed (BT off)
    [BatteryMonitor_lowpower.ino]
2024-03-16 Fix negative current offset bug Allow in APP to set pass phrase if not connected
    [BatteryMonitor_ADS1115.ino]
